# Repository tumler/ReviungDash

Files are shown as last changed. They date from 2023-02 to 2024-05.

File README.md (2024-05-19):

# REVIUNGDASH

## REVIUNGDASH47

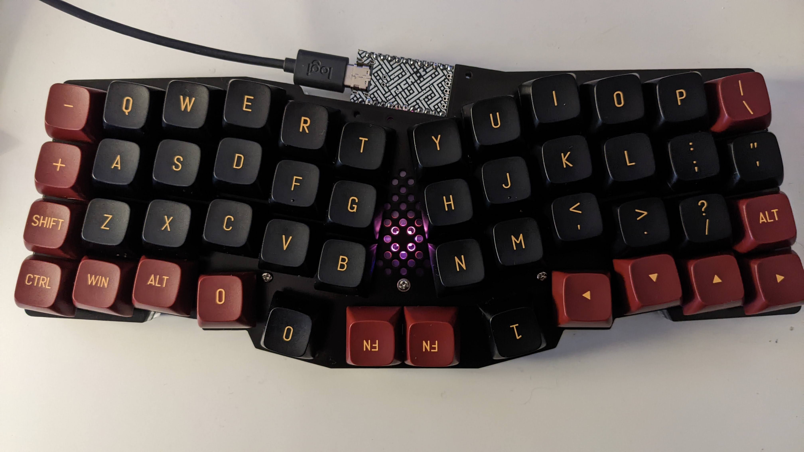
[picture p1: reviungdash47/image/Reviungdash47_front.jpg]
REVIUNG47 Front
  
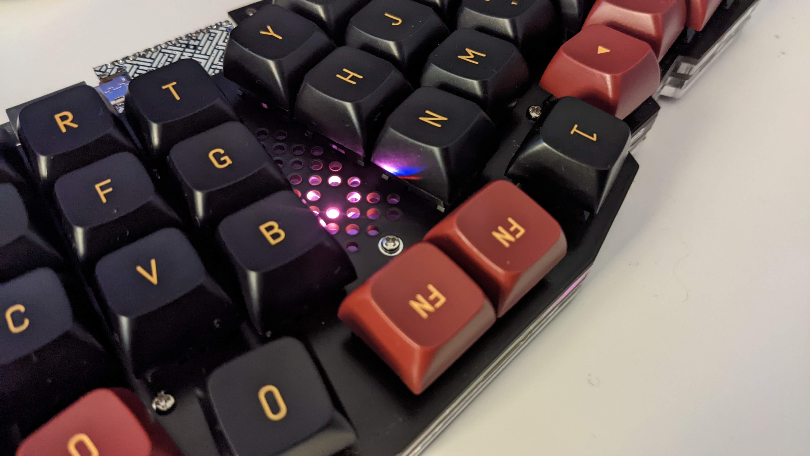
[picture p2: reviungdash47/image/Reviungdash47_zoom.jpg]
REVIUNG47 Zoom
  
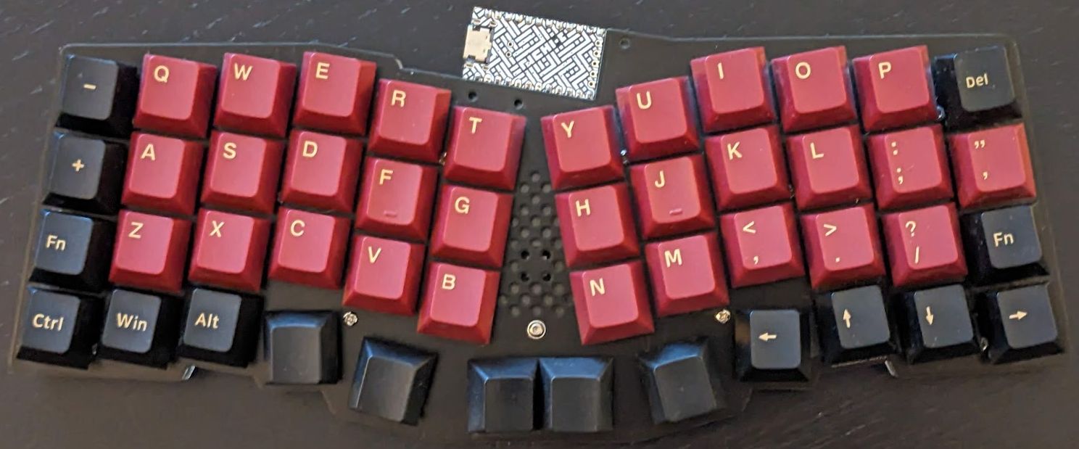
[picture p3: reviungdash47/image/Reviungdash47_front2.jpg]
REVIUNG47 Front 2
  

The REVIUNGDASH47 is 47/8 key column staggered keyboard. Inspired by the Reviung41
(& ERGODASH) hence the name!

[REVIUNGDASH47](reviungdash47/)

## REVIUNGDASH52

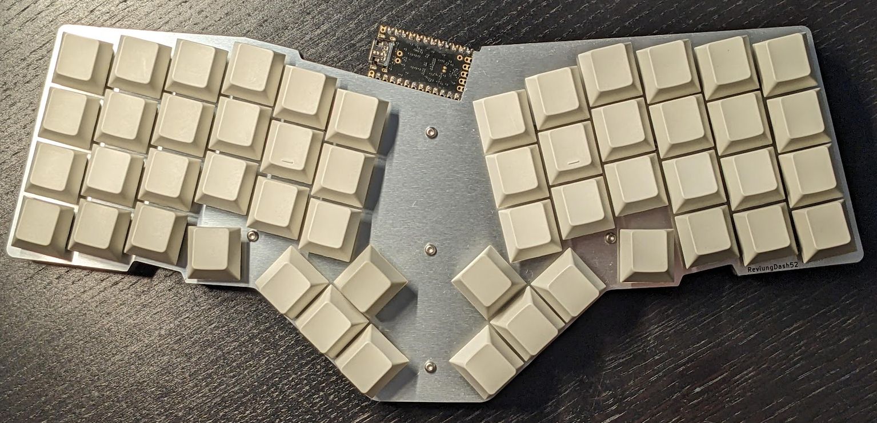
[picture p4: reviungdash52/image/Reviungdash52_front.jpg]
REVIUNG52 Front
  
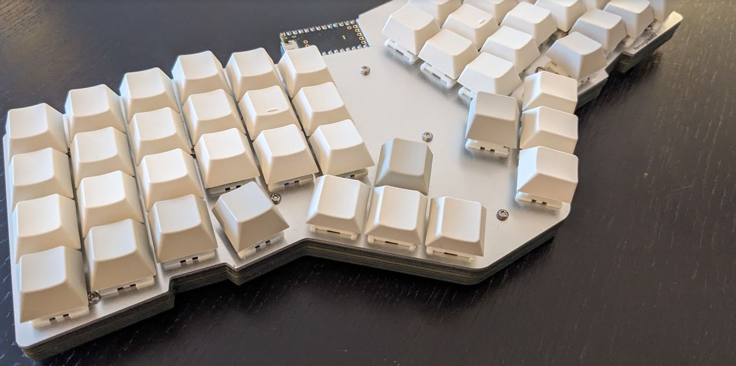
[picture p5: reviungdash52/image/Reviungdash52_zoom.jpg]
REVIUNG52 Zoom
  

The REVIUNGDASH52 is a 52 key column staggered keyboard. Based on the
REVIUNGDASH47 but with a larger thumb cluster.

[REVIUNGDASH52](reviungdash52/)

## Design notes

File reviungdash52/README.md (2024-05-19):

# REVIUNGDASH52

REVIUNG52 Front  
REVIUNG52 Zoom  

The REVIUNGDASH52 is a 52 key column staggered keyboard. Based on the
REVIUNGDASH47 but with a larger thumb cluster.

[REVIUNGDASH52](reviungdash52/)
The REVIUNGDASH47 is 47/8 key column staggered keyboard. Inspired by the Reviung41
(& ERGODASH) hence the name!

Differences between the REVIUNGDASH47:

* Addition of a thumb cluster - inspired by the Ergodash cluster
    * 2 Extra thumb keys each side
* Left / Right sides further apart to accomodate thumb cluster, while remaining
as close as possible to remain small yet comfortable
* Every layer designed as PCBs (could easily be swapped out for acrylic / metal layers)

## Parts list  

* Top plate (PCB / Metal) 1.6mm --- 1
* Inner w/ MCU Cutout 1.2mm --- 4
* PCB 1.6mm --- 1
* Inner without MCU Cutout 1.6mm --- 1
* Bottom Plate 1.6mm --- 1

* MCU (ProMicro or RP2040 that has the same dimensions as a ProMicro)

* Using Magnets as feet / standoffs:
* M2 Screw 5mm --- 22 pieces
* M2 Screw 6mm --- 4 pieces (to attach the magnets)
* Through-hole M3 Magnets --- 4 pieces (+ as many as you need for the height you want for the standoffs)

* No standoffs (or using another system):
* M2 Screw 5mm --- 26 pieces

* Rubber Feet --- 6 pieces (might require different sizes on the 2 internal legs - see photos)

* Diode [1N4148 SMD] --- 52 pieces  
* MX compatible key switch --- 52 pieces  

* Keycaps
* USB-C Cable --- 1

## Firmware

Based on QMK

* Works with VIAL UI (layout provided)
* QMK Config (layout provided - has not been tested)

[Vial-QMK Firmware](https://github.com/tumler/vial-qmk/tree/Add_ReviungDash_Keyboards)

## Build Guide

* See Reviung41 guide

[Build guide](https://reviung.com/build-guide/391/)

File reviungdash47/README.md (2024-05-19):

# REVIUNGDASH47

REVIUNG47 Front  
REVIUNG47 Zoom  

The REVIUNGDASH47 is 47/8 key column staggered keyboard. Inspired by the Reviung41
(& ERGODASH) hence the name!

Differences between the REVIUNG41:

* Addition of 6 corner keys
* Spacebar can be either a single switch or have 2x 1u switches
(inspired by the Ergodash which allows choosing the thumb keys)
* The RGB led on the front was rerouted to be first (as I would rather have 1
led and don't use the underglow - this allows to not have to solder all the other
leds but they can be if wanted later)

## Parts list  

PCB --- 1 piece  
Top plate [PCB] --- 1  
Silicon sheet --- 1 sheet  
Middle acrylic plate (top) --- 1  
Middle acrylic plate (bottom) --- 1  
Bottom plate --- 1 piece  
ProMicro protective plate --- 4 types  
Acrylic spacer --- 3 pieces  
Spacer --- 11 pieces  
M2 screw 4mm --- 22 pcs  
M2 screw 10mm --- 3 pcs  
M2 nut --- 3 pcs  
Rubber feet --- 6 pieces  
Diode [1N4148 SMD] --- 47/8 pieces  
PCB socket for switch --- 47/8 pcs  
Tact switch --- 1 piece  
LED [WS2812B] --- 11 pieces  
Stabilizer --- 1 piece  

ProMicro --- 1  
Con through (spring pin header 12P) --- 2  
MX compatible key switch --- 47/8 pcs  
Keycaps (1u + optional 2u if a double space bar is used)
MicroUSB cable --- 1  

## Firmware

Based on QMK

* Works with VIAL UI (layout provided)
* QMK Config (layout provided - has not been tested)

[Vial-QMK Firmware](https://github.com/tumler/vial-qmk/tree/Add_ReviungDash47)

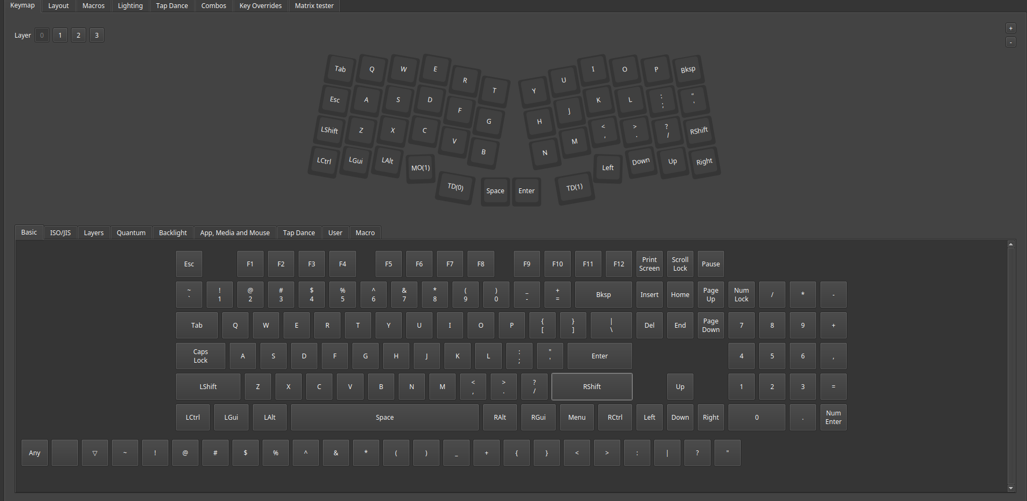
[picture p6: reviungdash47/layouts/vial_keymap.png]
REVIUNG47 Vial
  
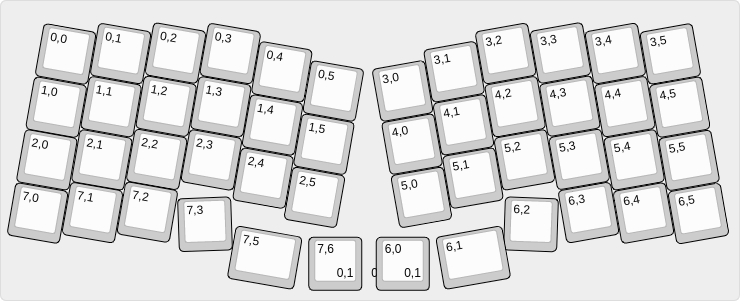
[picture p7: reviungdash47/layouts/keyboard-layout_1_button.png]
REVIUNG47 Vial
  
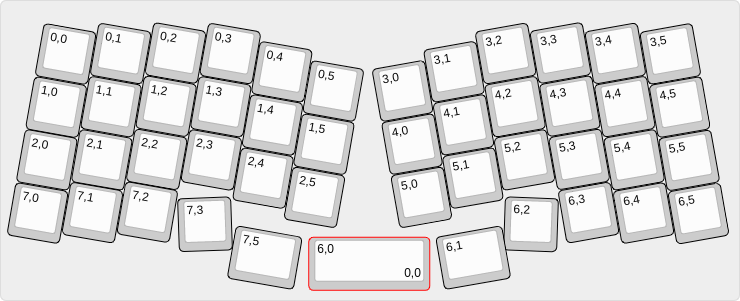
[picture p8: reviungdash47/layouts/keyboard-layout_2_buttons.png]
REVIUNG47 Vial
  

## Build Guide

* See Reviung41 guide

[Build guide](https://reviung.com/build-guide/391/)

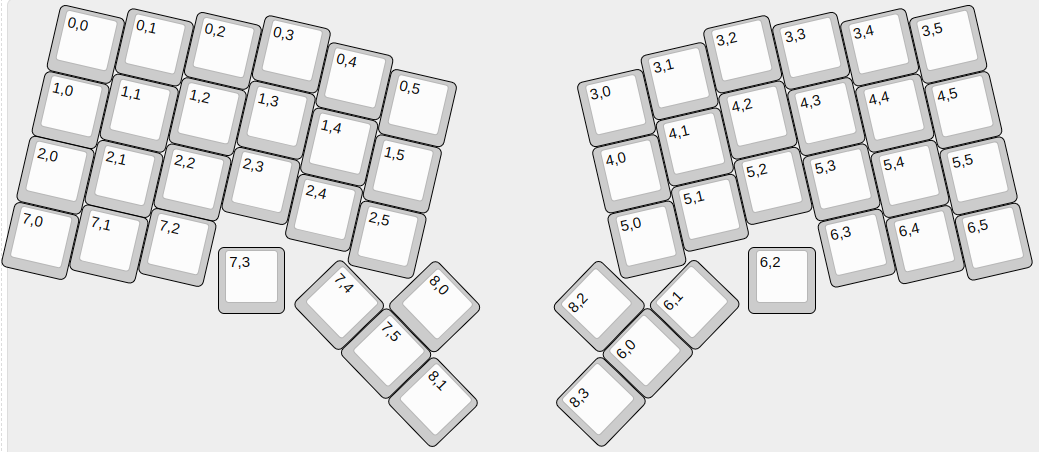
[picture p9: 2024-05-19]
reviungdash52/layouts/keyboard-layout.png

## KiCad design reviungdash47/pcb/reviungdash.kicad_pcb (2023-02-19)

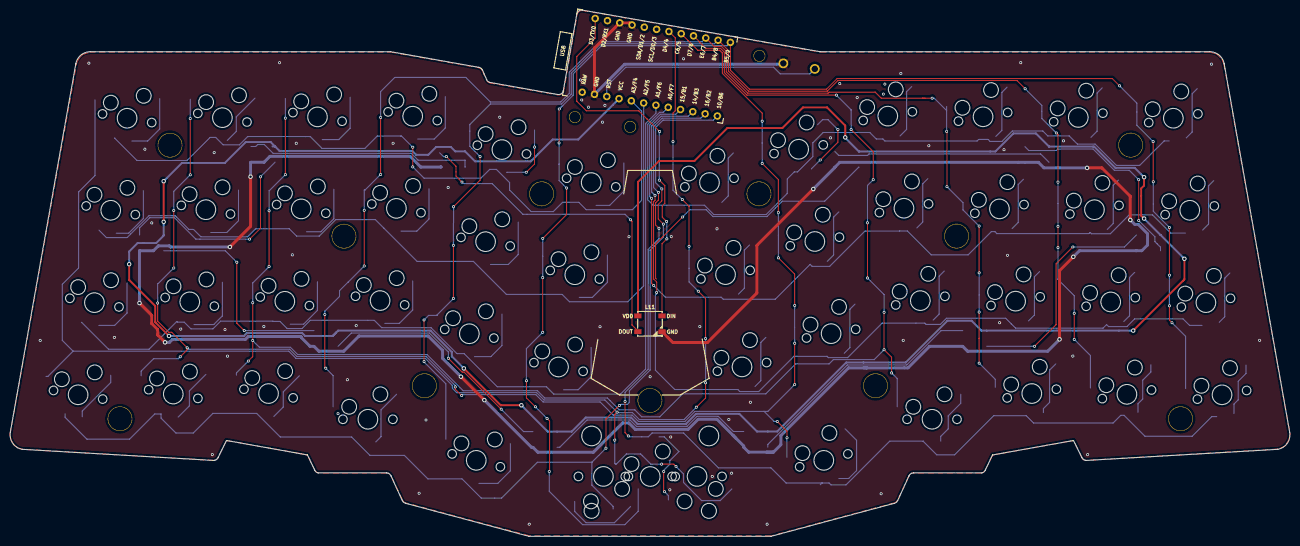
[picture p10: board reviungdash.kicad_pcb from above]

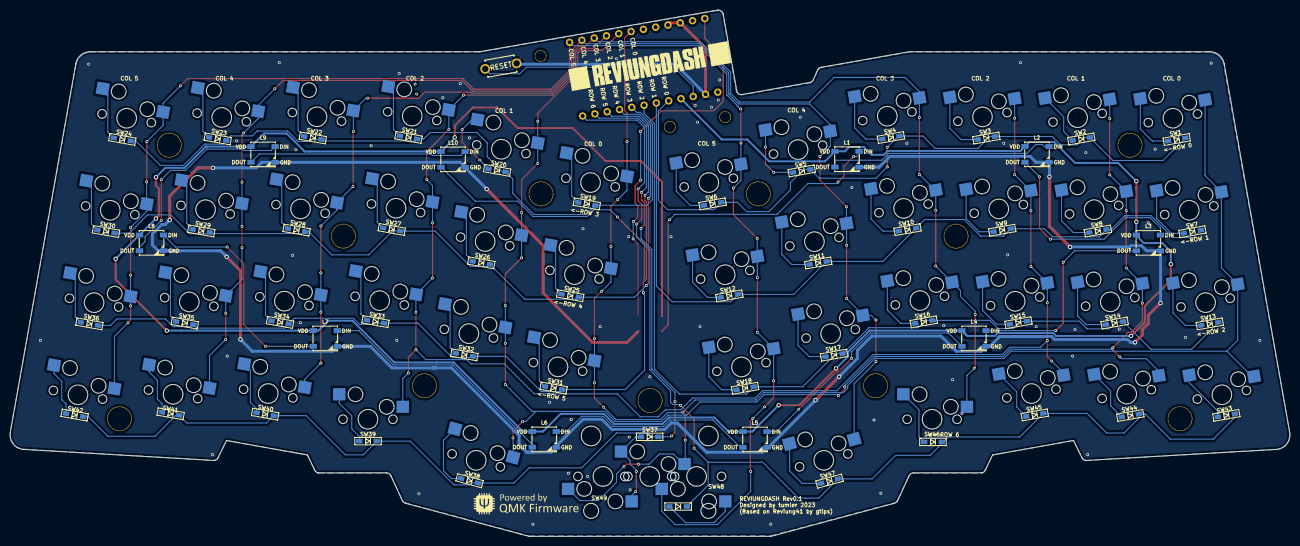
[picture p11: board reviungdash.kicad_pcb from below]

Board: 2 copper layers, 260.4 x 107.1 mm, 124 parts (59 on the bottom side), 76 nets.

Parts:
D1, D2, D3, D4, D5, D6, D7, D8, D9, D10, D11, D12, D13, D14, D15, D16, D17, D18, D19, D20, D21, D22, D23, D24, D25, D26, D27, D28, D29, D30, D31, D32, D33, D34, D35, D36, D37, D38, D39, D40, D41, D42, D43, D44, D45, D46, D47, D48: 1N4148W; D3_SMD_1side
H1: H1; HOLE
H2: H2; HOLE
H3: H3; HOLE
H4: H4; HOLE
H5: H5; HOLE
H6: H6; HOLE
H7: H7; HOLE
H8: H8; HOLE
H9: H9; HOLE
H10: H10; HOLE
H11: H11; HOLE
H12: H12; HOLE_2.2mm
H13: H13; HOLE_2.2mm
H14: H14; HOLE_2.2mm
L1, L2, L3, L4, L5, L6, L7, L8, L9, L10, L11: WS2812B; LED_WS2812B_PLCC4_5.0x5.0mm_P3.2mm
RESET1: SW_PUSH; ResetSW_1side
SW1, SW2, SW3, SW4, SW5, SW6, SW7, SW8, SW9, SW10, SW11, SW12, SW13, SW14, SW15, SW16, SW17, SW18, SW19, SW20, SW21, SW22, SW23, SW24, SW25, SW26, SW27, SW28, SW29, SW30, SW31, SW32, SW33, SW34, SW35, SW36, SW38, SW40, SW41, SW42, SW43, SW44, SW45, SW46, SW47, SW48, SW49: SW_PUSH; MXOnly-1U-Hotswap
SW37: SW_PUSH; MXOnly-2U-Hotswap-ReversedStabilizers
SW39: SW_2U_PUSH; MXOnly-1U-Hotswap
U1: ProMicro

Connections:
GND: L1.3 (VSS), L2.3 (VSS), L3.3 (VSS), L4.3 (VSS), L5.3 (VSS), L6.3 (VSS), L7.3 (VSS), L8.3 (VSS), L9.3 (VSS), L10.3 (VSS), L11.3 (VSS), RESET1.2, U1.3 (GND), U1.4 (GND), U1.23 (GND)
LED: L11.4 (DIN), U1.1 (TX0/D3)
unnamed: D1.2 (A), SW1.2
unnamed: D2.2 (A), SW2.2
unnamed: D3.2 (A), SW3.2
unnamed: D4.2 (A), SW4.2
unnamed: D5.2 (A), SW5.2
unnamed: D6.2 (A), SW6.2
unnamed: D7.2 (A), SW7.2
unnamed: D8.2 (A), SW8.2
unnamed: D9.2 (A), SW9.2
unnamed: D10.2 (A), SW10.2
unnamed: D11.2 (A), SW11.2
unnamed: D12.2 (A), SW12.2
unnamed: D13.2 (A), SW13.2
unnamed: D14.2 (A), SW14.2
unnamed: D15.2 (A), SW15.2
unnamed: D16.2 (A), SW16.2
unnamed: D17.2 (A), SW17.2
unnamed: D18.2 (A), SW18.2
unnamed: D19.2 (A), SW19.2
unnamed: D20.2 (A), SW20.2
unnamed: D21.2 (A), SW21.2
unnamed: D22.2 (A), SW22.2
unnamed: D23.2 (A), SW23.2
unnamed: D24.2 (A), SW24.2
unnamed: D25.2 (A), SW25.2
unnamed: D26.2 (A), SW26.2
unnamed: D27.2 (A), SW27.2
unnamed: D28.2 (A), SW28.2
unnamed: D29.2 (A), SW29.2
unnamed: D30.2 (A), SW30.2
unnamed: D31.2 (A), SW31.2
unnamed: D32.2 (A), SW32.2
unnamed: D33.2 (A), SW33.2
unnamed: D34.2 (A), SW34.2
unnamed: D35.2 (A), SW35.2
unnamed: D36.2 (A), SW36.2
unnamed: D37.2 (A), SW37.2, SW49.2
unnamed: D38.2 (A), SW38.2
unnamed: D39.2 (A), SW39.2
unnamed: D40.2 (A), SW40.2
unnamed: D41.2 (A), SW41.2
unnamed: L1.2 (DOUT), L2.4 (DIN)
unnamed: L1.4 (DIN), L11.2 (DOUT)
unnamed: L2.2 (DOUT), L3.4 (DIN)
unnamed: L3.2 (DOUT), L4.4 (DIN)
unnamed: L4.2 (DOUT), L5.4 (DIN)
unnamed: L5.2 (DOUT), L6.4 (DIN)
unnamed: L6.2 (DOUT), L7.4 (DIN)
unnamed: L7.2 (DOUT), L8.4 (DIN)
unnamed: L8.2 (DOUT), L9.4 (DIN)
unnamed: L9.2 (DOUT), L10.4 (DIN)
unnamed: D42.2 (A), SW42.2
unnamed: D43.2 (A), SW43.2
unnamed: D44.2 (A), SW44.2
unnamed: D45.2 (A), SW45.2
unnamed: D46.2 (A), SW46.2
unnamed: D47.2 (A), SW47.2
unnamed: D48.2 (A), SW48.2
VCC: L1.1 (VDD), L2.1 (VDD), L3.1 (VDD), L4.1 (VDD), L5.1 (VDD), L6.1 (VDD), L7.1 (VDD), L8.1 (VDD), L9.1 (VDD), L10.1 (VDD), L11.1 (VDD), U1.21 (VCC)
col0: SW1.1, SW7.1, SW13.1, SW19.1, SW25.1, SW31.1, SW37.1, SW43.1, SW49.1, U1.7 (4/D4)
col1: SW2.1, SW8.1, SW14.1, SW20.1, SW26.1, SW32.1, SW38.1, SW44.1, U1.8 (5/C6)
col2: SW3.1, SW9.1, SW15.1, SW21.1, SW27.1, SW33.1, SW39.1, SW45.1, U1.9 (6/D7)
col3: SW4.1, SW10.1, SW16.1, SW22.1, SW28.1, SW34.1, SW40.1, SW46.1, U1.10 (7/E6)
col4: SW5.1, SW11.1, SW17.1, SW23.1, SW29.1, SW35.1, SW41.1, SW47.1, U1.11 (8/B4)
col5: SW6.1, SW12.1, SW18.1, SW24.1, SW30.1, SW36.1, SW42.1, SW48.1, U1.12 (9/B5)
reset: RESET1.1, U1.22 (RST)
row0: D1.1 (K), D2.1 (K), D3.1 (K), D4.1 (K), D5.1 (K), D6.1 (K), U1.20 (F4/A3)
row1: D7.1 (K), D8.1 (K), D9.1 (K), D10.1 (K), D11.1 (K), D12.1 (K), U1.19 (F5/A2)
row2: D13.1 (K), D14.1 (K), D15.1 (K), D16.1 (K), D17.1 (K), D18.1 (K), U1.18 (F6/A1)
row3: D19.1 (K), D20.1 (K), D21.1 (K), D22.1 (K), D23.1 (K), D24.1 (K), U1.17 (F7/A0)
row4: D25.1 (K), D26.1 (K), D27.1 (K), D28.1 (K), D29.1 (K), D30.1 (K), U1.16 (B1/15)
row5: D31.1 (K), D32.1 (K), D33.1 (K), D34.1 (K), D35.1 (K), D36.1 (K), U1.15 (B3/14)
row6: D37.1 (K), D38.1 (K), D39.1 (K), D40.1 (K), D41.1 (K), D42.1 (K), U1.14 (B2/16)
row7: D43.1 (K), D44.1 (K), D45.1 (K), D46.1 (K), D47.1 (K), D48.1 (K), U1.13 (B6/10)

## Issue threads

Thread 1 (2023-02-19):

Align the screw hole of the PCB with the case

tumler, 2023-02-19:
The 2x lower screw holes on either side were repositioned as more keys were added, the PCB had these holes moved first and then the acrylic cases. There is a slight difference between the PCB and acrylic layers (less then 0.5mm) - these still work fine as is but it would be good to align them in the next version.

Update the PCB to align with the acrylic layers.

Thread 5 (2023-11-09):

gerber files

achengli, 2023-11-09:
Hello,

I don't know if it would be too much trouble but could you upload the gerber files?

thanks!
